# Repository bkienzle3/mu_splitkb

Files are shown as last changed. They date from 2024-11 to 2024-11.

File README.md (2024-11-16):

# mu_splitkb
Mu Split Keyboard - 36-key columnar staggered split keyboard

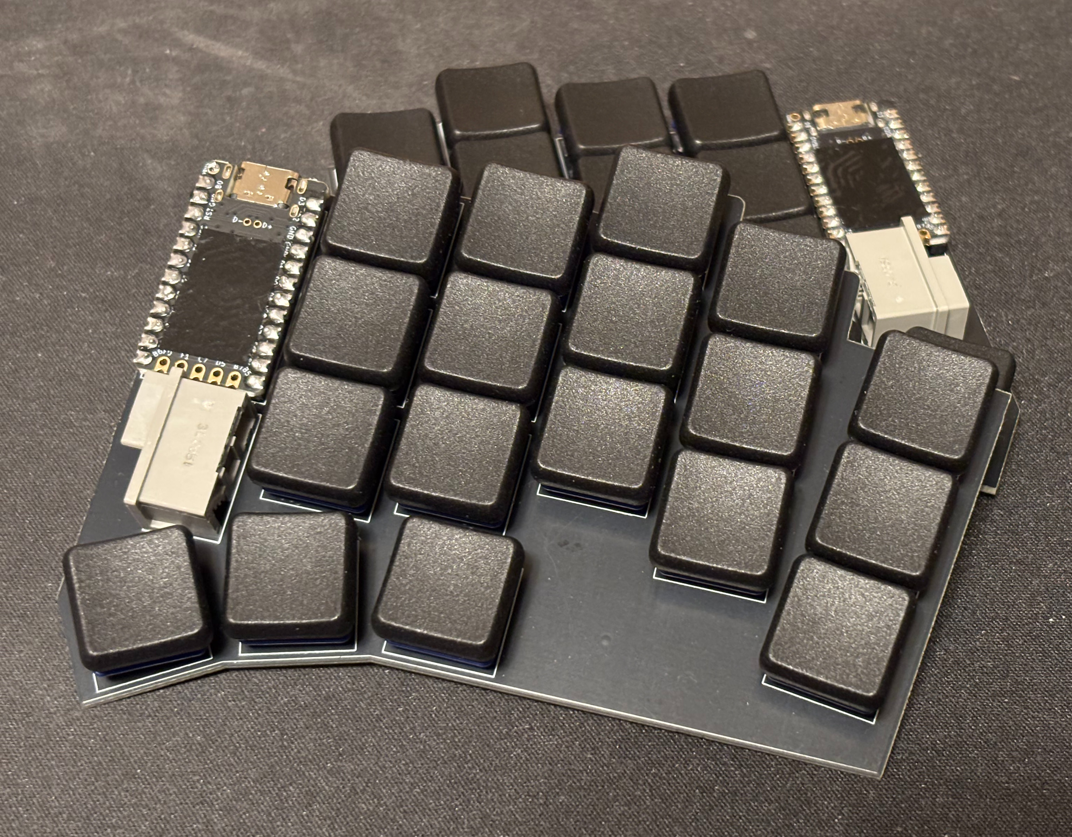
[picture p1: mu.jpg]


## Firmware

Firmware is located in qmk_firmware. I'm planning to have this added into the official repo.
Keymaps are based on Miryoku (manna-harbour/miryoku), with my own customizations, of course.

## Bill of materials

Kailh Choc V1 key switches x 36
<br>Kailh Choc V1 Hotswap sockets x 36
<br>Elite-C/ProMicro x 2
<br>1N4148 MiniMELF diode x 36
<br>TM5RF-4450 x 2
<br>4P4C cable x 1

## Inspiration

While this keyboard was created from scratch, it was heavily inspired by the Sweep (davidphilipbarr/Sweep).

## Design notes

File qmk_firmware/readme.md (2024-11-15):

# mu

mu

*A short description of the keyboard/project*

* Keyboard Maintainer: [bkienzle3](https://github.com/bkienzle3)
* Hardware Supported: *The PCBs, controllers supported*
* Hardware Availability: *Links to where you can find this hardware*

Make example for this keyboard (after setting up your build environment):

    make mu:default

Flashing example for this keyboard:

    make mu:default:flash

See the [build environment setup](https://docs.qmk.fm/#/getting_started_build_tools) and the [make instructions](https://docs.qmk.fm/#/getting_started_make_guide) for more information. Brand new to QMK? Start with our [Complete Newbs Guide](https://docs.qmk.fm/#/newbs).

## Bootloader

Enter the bootloader in 3 ways:

* **Bootmagic reset**: Hold down the key at (0,0) in the matrix (usually the top left key or Escape) and plug in the keyboard
* **Physical reset button**: Briefly press the button on the back of the PCB - some may have pads you must short instead
* **Keycode in layout**: Press the key mapped to `QK_BOOT` if it is available

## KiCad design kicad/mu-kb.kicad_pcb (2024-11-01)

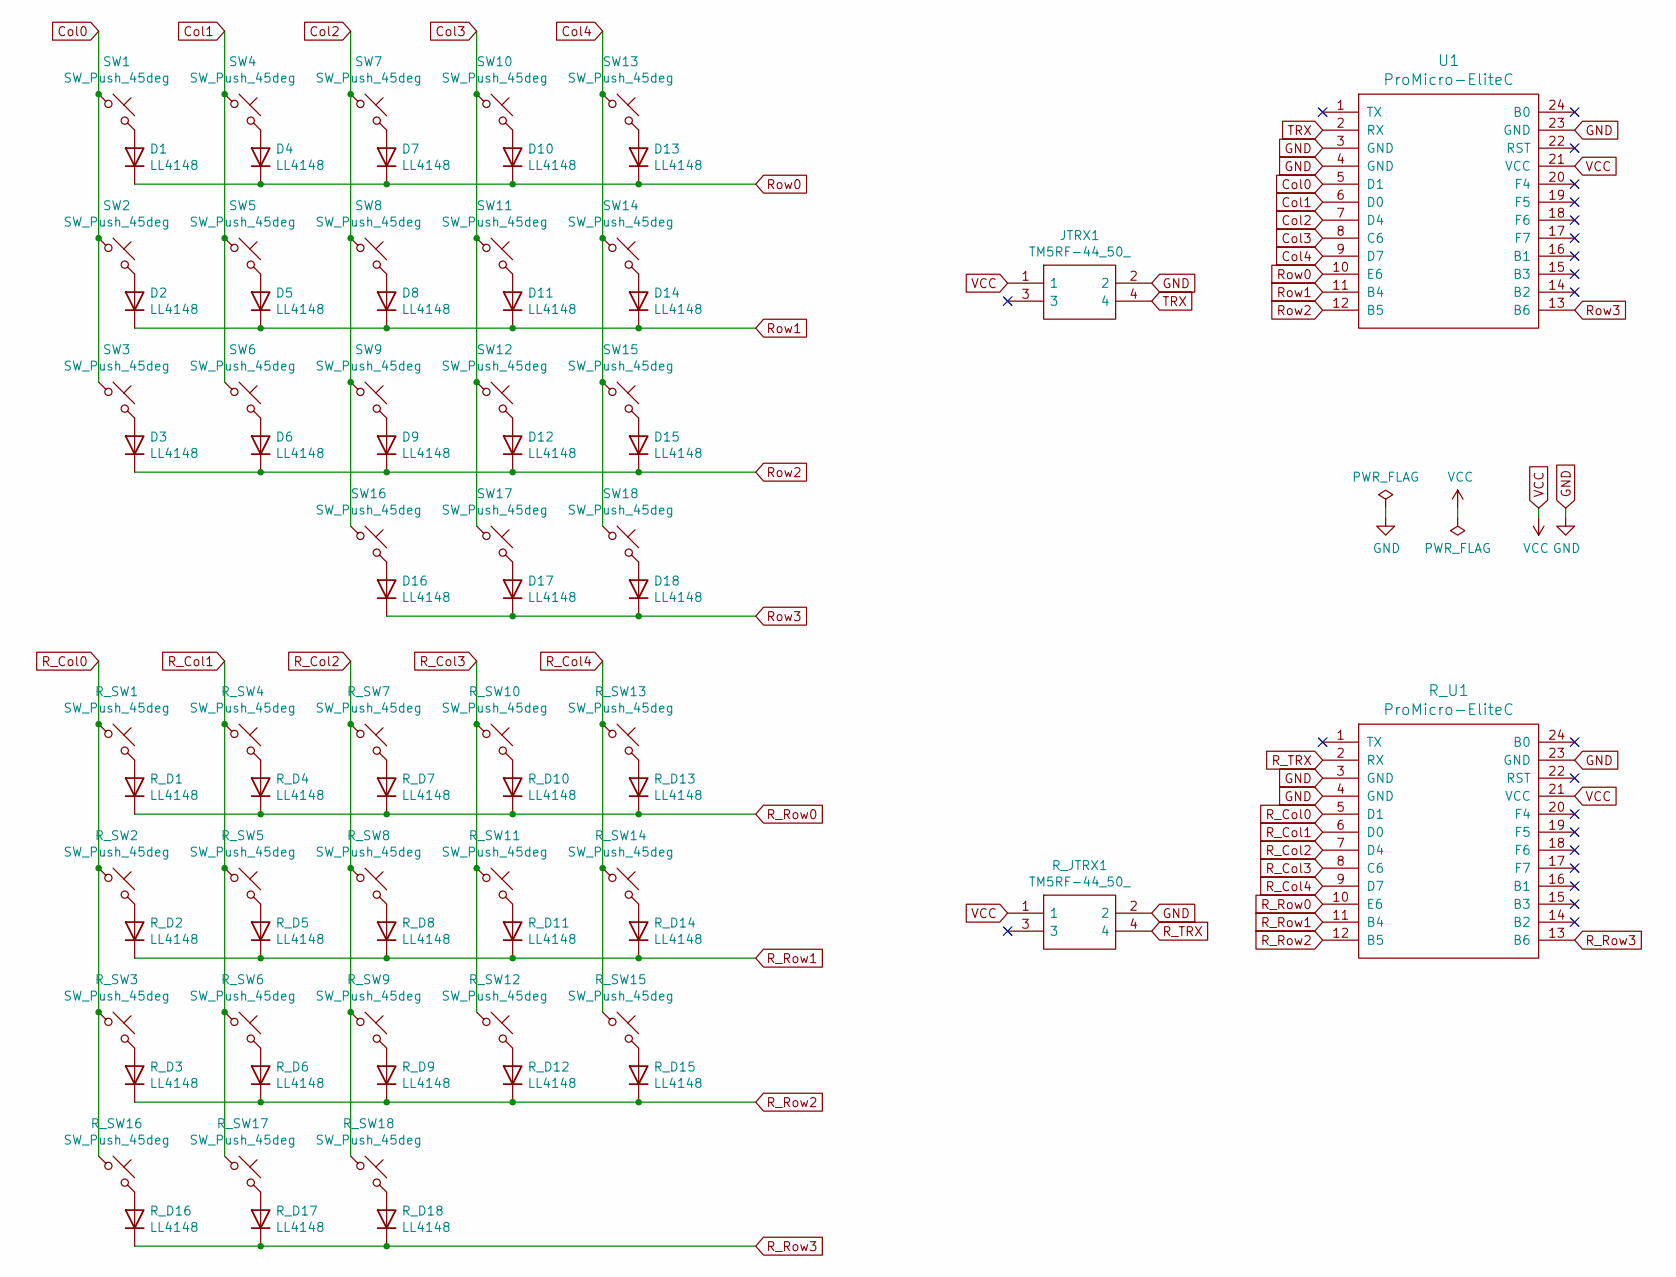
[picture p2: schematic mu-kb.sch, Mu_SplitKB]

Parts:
D1, D2, D3, D4, D5, D6, D7, D8, D9, D10, D11, D12, D13, D14, D15, D16, D17, D18: LL4148; D_MiniMELF
JTRX1: TM5RF-44_50_; TM5RF4450; Manufacturer_Part_Number TM5RF-44(50); Mouser Part Number 798-TM5RF4450
R_D1, R_D2, R_D3, R_D4, R_D5, R_D6, R_D7, R_D8, R_D9, R_D10, R_D11, R_D12, R_D13, R_D14, R_D15, R_D16, R_D17, R_D18: LL4148; D_MiniMELF
R_JTRX1: TM5RF-44_50_; TM5RF4450; Manufacturer_Part_Number TM5RF-44(50); Mouser Part Number 798-TM5RF4450
R_SW1, R_SW2, R_SW3, R_SW4, R_SW5, R_SW6, R_SW7, R_SW8, R_SW9, R_SW10, R_SW11, R_SW12, R_SW13, R_SW14, R_SW15, R_SW16, R_SW17, R_SW18: SW_Push_45deg; SW_Hotswap_Kailh_Choc_V1
R_U1: ProMicro-EliteC; ProMicro
SW1, SW2, SW3, SW4, SW5, SW6, SW7, SW8, SW9, SW10, SW11, SW12, SW13, SW14, SW15, SW16, SW17, SW18: SW_Push_45deg; SW_Hotswap_Kailh_Choc_V1
U1: ProMicro-EliteC; ProMicro

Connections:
Col0: SW1.1, SW2.1, SW3.1, U1.5 (D1)
Col1: SW4.1, SW5.1, SW6.1, U1.6 (D0)
Col2: SW7.1, SW8.1, SW9.1, SW16.1, U1.7 (D4)
Col3: SW10.1, SW11.1, SW12.1, SW17.1, U1.8 (C6)
Col4: SW13.1, SW14.1, SW15.1, SW18.1, U1.9 (D7)
GND: JTRX1.2, R_JTRX1.2, R_U1.3 (GND), R_U1.4 (GND), R_U1.23 (GND), U1.3 (GND), U1.4 (GND), U1.23 (GND)
unnamed: D1.2 (A), SW1.2
unnamed: D2.2 (A), SW2.2
unnamed: D3.2 (A), SW3.2
unnamed: D4.2 (A), SW4.2
unnamed: D5.2 (A), SW5.2
unnamed: D6.2 (A), SW6.2
unnamed: D7.2 (A), SW7.2
unnamed: D8.2 (A), SW8.2
unnamed: D9.2 (A), SW9.2
unnamed: D10.2 (A), SW10.2
unnamed: D11.2 (A), SW11.2
unnamed: D12.2 (A), SW12.2
unnamed: D13.2 (A), SW13.2
unnamed: D14.2 (A), SW14.2
unnamed: D15.2 (A), SW15.2
unnamed: D16.2 (A), SW16.2
unnamed: D17.2 (A), SW17.2
unnamed: D18.2 (A), SW18.2
unnamed: R_D1.2 (A), R_SW1.2
unnamed: R_D2.2 (A), R_SW2.2
unnamed: R_D3.2 (A), R_SW3.2
unnamed: R_D4.2 (A), R_SW4.2
unnamed: R_D5.2 (A), R_SW5.2
unnamed: R_D6.2 (A), R_SW6.2
unnamed: R_D7.2 (A), R_SW7.2
unnamed: R_D8.2 (A), R_SW8.2
unnamed: R_D9.2 (A), R_SW9.2
unnamed: R_D10.2 (A), R_SW10.2
unnamed: R_D11.2 (A), R_SW11.2
unnamed: R_D12.2 (A), R_SW12.2
unnamed: R_D13.2 (A), R_SW13.2
unnamed: R_D14.2 (A), R_SW14.2
unnamed: R_D15.2 (A), R_SW15.2
unnamed: R_D16.2 (A), R_SW16.2
unnamed: R_D17.2 (A), R_SW17.2
unnamed: R_D18.2 (A), R_SW18.2
R_Col0: R_SW1.1, R_SW2.1, R_SW3.1, R_SW16.1, R_U1.5 (D1)
R_Col1: R_SW4.1, R_SW5.1, R_SW6.1, R_SW17.1, R_U1.6 (D0)
R_Col2: R_SW7.1, R_SW8.1, R_SW9.1, R_SW18.1, R_U1.7 (D4)
R_Col3: R_SW10.1, R_SW11.1, R_SW12.1, R_U1.8 (C6)
R_Col4: R_SW13.1, R_SW14.1, R_SW15.1, R_U1.9 (D7)
R_Row0: R_D1.1 (K), R_D4.1 (K), R_D7.1 (K), R_D10.1 (K), R_D13.1 (K), R_U1.10 (E6)
R_Row1: R_D2.1 (K), R_D5.1 (K), R_D8.1 (K), R_D11.1 (K), R_D14.1 (K), R_U1.11 (B4)
R_Row2: R_D3.1 (K), R_D6.1 (K), R_D9.1 (K), R_D12.1 (K), R_D15.1 (K), R_U1.12 (B5)
R_Row3: R_D16.1 (K), R_D17.1 (K), R_D18.1 (K), R_U1.13 (B6)
R_TRX: R_JTRX1.4, R_U1.2 (RX)
Row0: D1.1 (K), D4.1 (K), D7.1 (K), D10.1 (K), D13.1 (K), U1.10 (E6)
Row1: D2.1 (K), D5.1 (K), D8.1 (K), D11.1 (K), D14.1 (K), U1.11 (B4)
Row2: D3.1 (K), D6.1 (K), D9.1 (K), D12.1 (K), D15.1 (K), U1.12 (B5)
Row3: D16.1 (K), D17.1 (K), D18.1 (K), U1.13 (B6)
TRX: JTRX1.4, U1.2 (RX)
VCC: JTRX1.1, R_JTRX1.1, R_U1.21 (VCC), U1.21 (VCC)

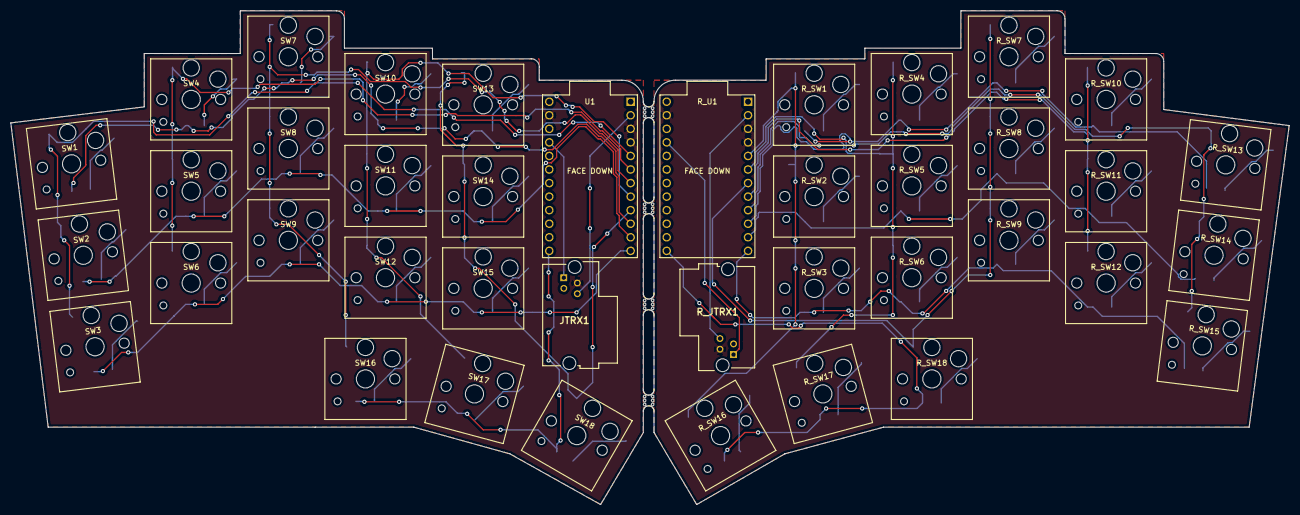
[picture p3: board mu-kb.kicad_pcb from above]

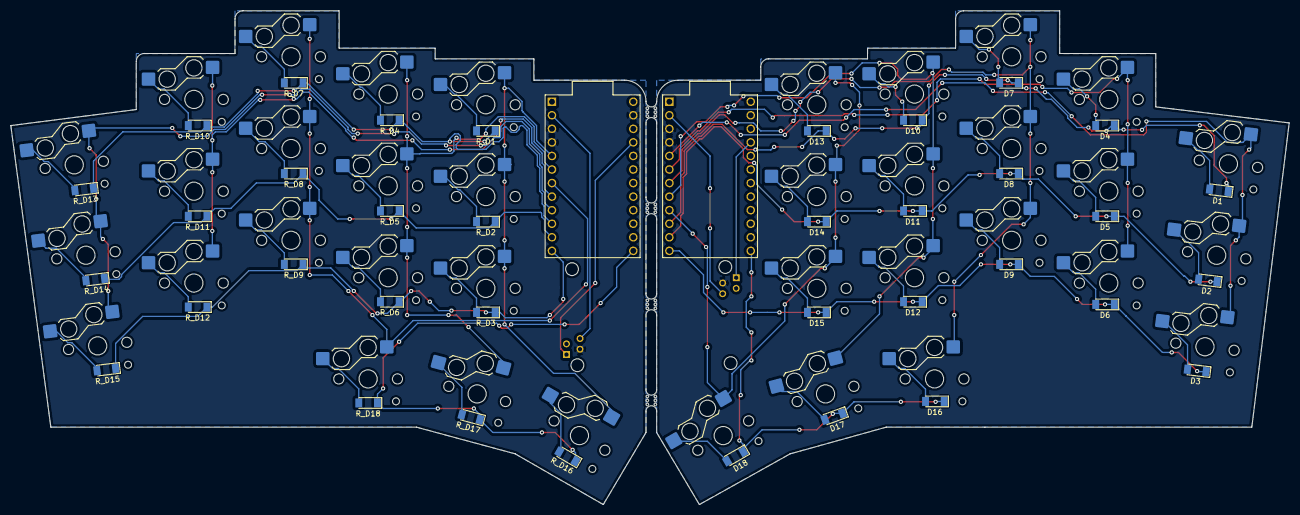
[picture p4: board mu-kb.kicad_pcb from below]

Board: 2 copper layers, 239.5 x 92.5 mm, 80 parts (36 on the bottom side), 58 nets.

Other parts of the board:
mouse-bite-2mm-slot, mouse-bite-2mm-slot#2, mouse-bite-2mm-slot#3, mouse-bite-2mm-slot#4: VAL**; mouse-bite-2mm-slot

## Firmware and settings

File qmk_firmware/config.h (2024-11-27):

// Copyright 2024 bkienzle3 (@bkienzle3)
// SPDX-License-Identifier: GPL-2.0-or-later

#pragma once

/*
 * Feature disable options
 *  These options are also useful to firmware size reduction.
 */

/* disable debug print */
//#define NO_DEBUG

/* disable print */
//#define NO_PRINT

/* disable action features */
//#define NO_ACTION_LAYER
//#define NO_ACTION_TAPPING
#define NO_ACTION_ONESHOT

// handedness
#define EE_HANDS

// mouse settings
#define MOUSEKEY_INTERVAL 16
#define MOUSEKEY_TIME_TO_MAX 60
#define MOUSEKEY_MAX_SPEED 15
#define MOUSEKEY_MOVE_DELTA 3
#define MOUSEKEY_DELAY 10
#define MOUSEKEY_WHEEL_DELAY 100
#define MOUSEKEY_WHEEL_INTERVAL 50
#define MOUSEKEY_WHEEL_TIME_TO_MAX 100

// homerow mods
#define TAPPING_TERM 200
#define QUICK_TAP_TERM 90
#define TAPPING_TERM_PER_KEY

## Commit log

2024-11-01 completed v2
    [mu-kb-B_Cu.gbl, mu-kb-B_Mask.gbs, mu-kb-B_Paste.gbp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]
2024-11-14 cleanup directories
    [mu-kb.kicad_pcb, mu-kb.sch]
